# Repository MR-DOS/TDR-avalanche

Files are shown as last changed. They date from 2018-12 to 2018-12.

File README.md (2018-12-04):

# TDR-avalanche
----
## Description
Simple flat-top avalanche pulser with integrated power supply for the avalanche transistor circuit and trigger circuitry. 

----
## Overview
This pulser was made in hope to use it to measure reflections on cables. However, using the transistor 2SC5773, it was not possible to obtain faster risetime than about 700 ps. This allows to measure reflections, but the resolution is quite limited due to the shape of the pulse (slow risetime and a backlash after the falling edge). Maybe using some other transistor and changing the compensation circuitry, it could be made better. Since there are many PECL buffers with rise and fall times faster than 200 ps (and reproducible), the next one will use some IC to generate the pulses. Also, generating short rectangular pulse is not very good if you want to postprocess the data, because you would need to run a decorrelation to find out what is happening on the cable. Using a long rectangular pulse (with infinitesimally fast edges) where all of the reflected energy comes back before the falling edge allows you to derive the signal which in turn gives you impulse response.

----
## Features
### Power supplies
The pulser contains a 40V power supply followed by denoising network and 6V - 35V regulated linear supply to set the avalanche voltage. The whole board is powered from 5V using Mini USB-B, consuming less than 100 mA.

### Avalanche pulser
The avalanche pulser uses 2SC5773 transistor (6V NPN, fT=10.8 GHz @ 50 mA). The compensation circuitry makes the output pulse a nice clean rectangular pulse with a flat top with no visible ringing (invisible with 1 GHz oscilloscope, to be precise), however there is a not very nice backlash after the falling edge (see pictures). The transistor does not self-avalanche when set properly, it has to be triggered by external source. I used 8-10 kHz triggering during the development and use. There are 2 SMA connectors, one for coaxial cable where energy for the pulse is stored (length of the cable determines length of the pulse) and one where the pulses are output.

### Trigger circuitry
The trigger circuitry triggers avalanche on rising edge of the input trigger signal. There is RC circuit which sets the time between the trigger and avalanche. However, it seems to have quite large jitter. There is also trigger output which you can connect to scilloscope (the avalanche happens on falling edge of the TRIG OUT). The trigger circuitry can be inhibited using the jumper JP1 when tuning the avalanche voltage.

### Attenuators
There are 2 attenuator sections giving 11.3 and 7.9 dB attenuation. The first one is mandatory as it is an impedance matching circuit. The second one is just a normal attenuator and can be omitted.

----
## How to use it as a simple standalone time-domain reflectometer
Connect square wave generator to the SYNC\_IN port. Connect an oscilloscope to the SYNC\_OUT port and to the PULSE\_OUT port.
Connect the coaxial cable to be measured to the STORAGE_COAX port. The cable MUST NOT have any shorts in it or any low impedance termination, because it is connected to the collector network and it would load the 200k resistor and the transistor would not avalanche. This severely limits the useability, so this mode is not recommended.

----
## How to use it as a pulser for general use
Connect square wave generator to the SYNC\_IN port.
Connect storage coaxial cable to the STORAGE_COAX port. You should use some 50 Ohm cable with low losses, ideally some rigid or semirigid cable. I used RG-174 because I had a lot of it on hand and the circuit is tweaked for use with the RG-174 (I used about one meter of the cable which gave me about 8 ns long pulse). Connect the PULSE\_OUT port to anything you want (50 Ohm terminated).

----
## Images
Oscillogram of the whole pulse:
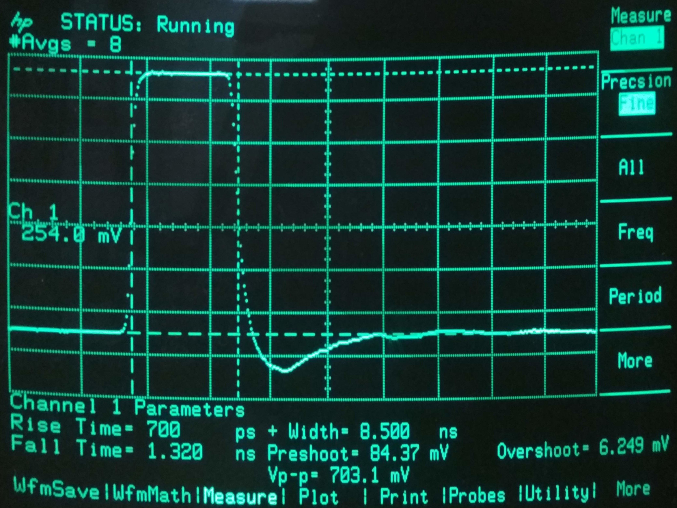
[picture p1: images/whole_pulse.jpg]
Oscillogram of the whole pulse

Oscillogram of the rising edge:
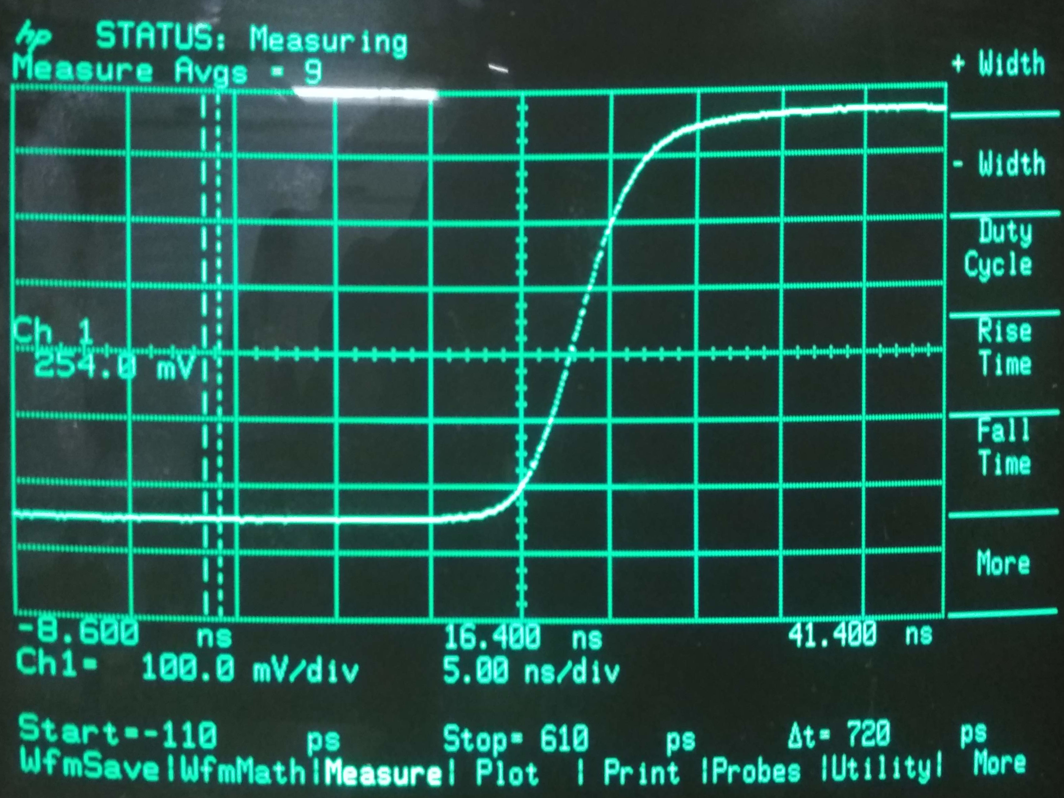
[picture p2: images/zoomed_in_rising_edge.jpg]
Oscillogram of the rising edge

Oscillogram of the zoomed in pulse:
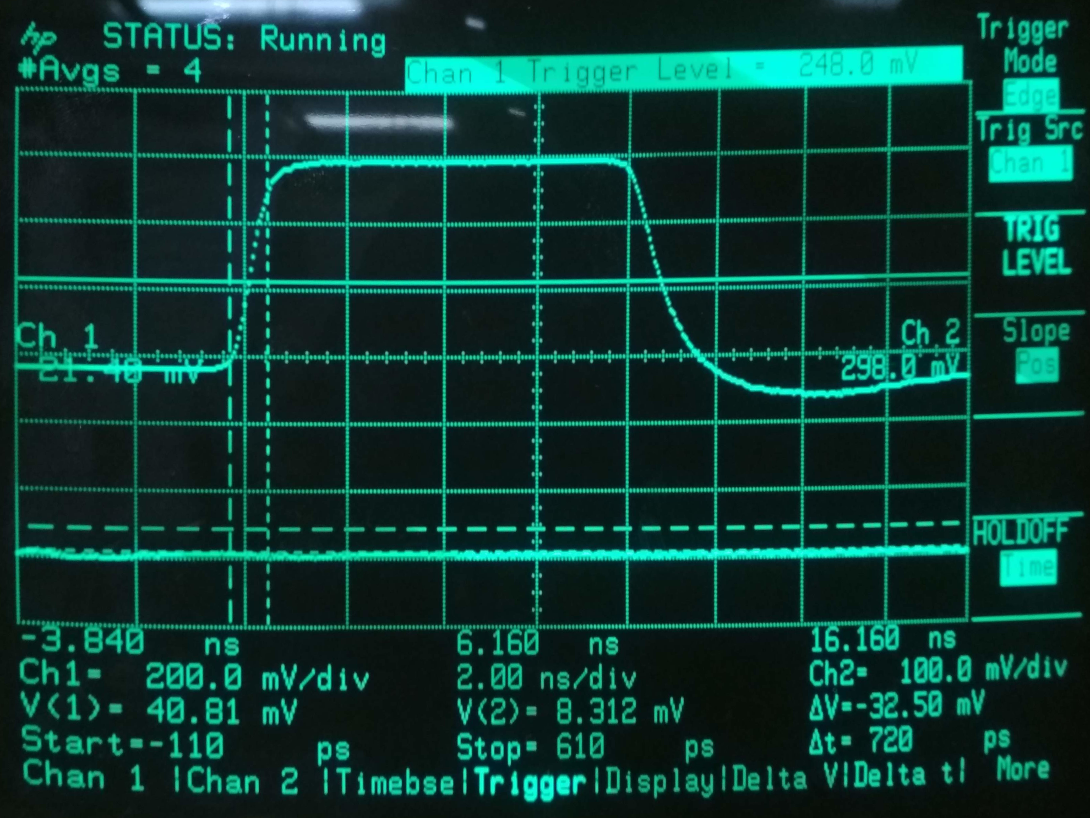
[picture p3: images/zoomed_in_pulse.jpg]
Oscillogram of the zoomed in pulse

Picture of the made and assembled PCB:
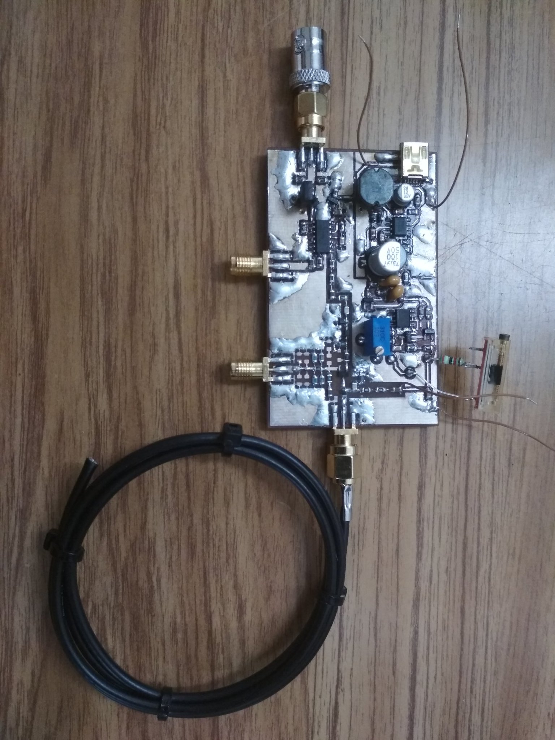
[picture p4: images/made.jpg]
Picture of the made and assembled PCB

Picture of the PCB connected to oscilloscope and generator:
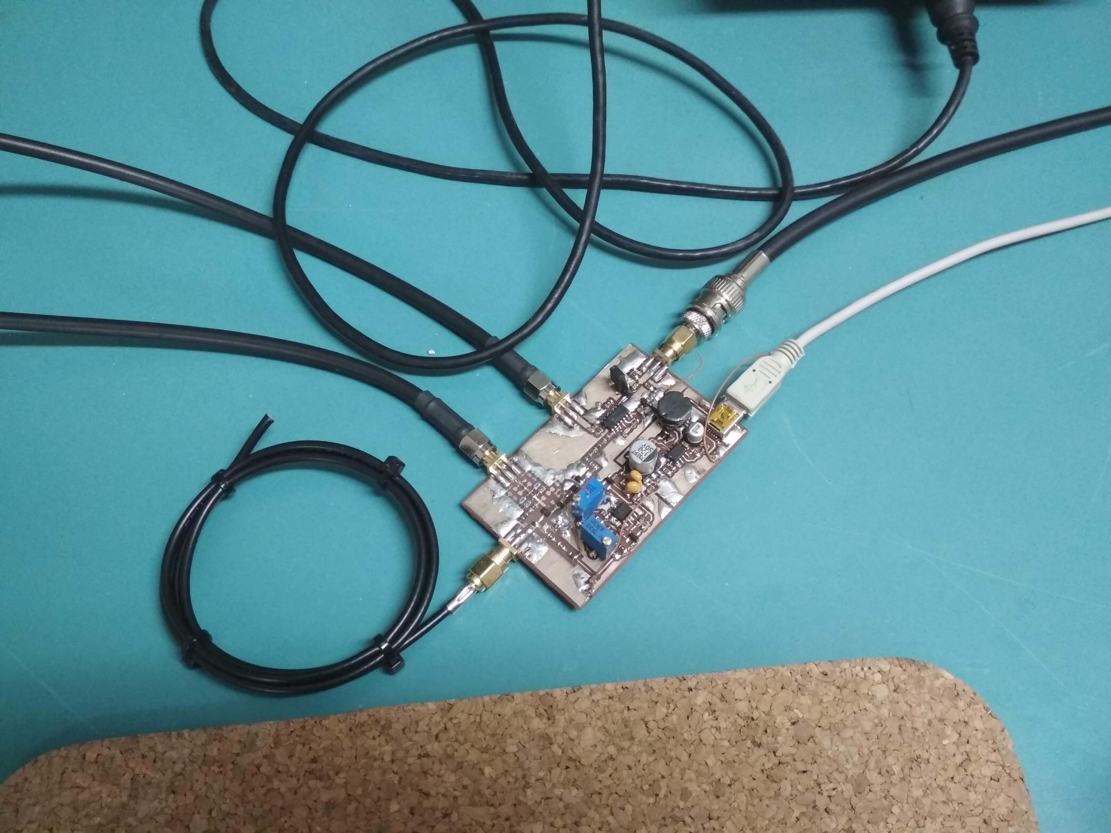
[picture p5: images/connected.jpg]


----
## Reference
[AN-94: Slew Rate Verification for Wideband Amplifiers](https://www.analog.com/media/en/technical-documentation/application-notes/an94f.pdf)

[AN-72: A Seven-Nanosecond Comparator for Single Supply Operation](https://www.analog.com/media/en/technical-documentation/application-notes/an72f.pdf)

[Tweet with photo of the etched PCB](https://twitter.com/polasek_petr/status/1063875099940532225)

[Tweet with photos of the etched, drilled and assembled PCB](https://twitter.com/polasek_petr/status/1064328075725426688)

[Tweet with measured output of the circuit](https://twitter.com/polasek_petr/status/1064698462539866112)

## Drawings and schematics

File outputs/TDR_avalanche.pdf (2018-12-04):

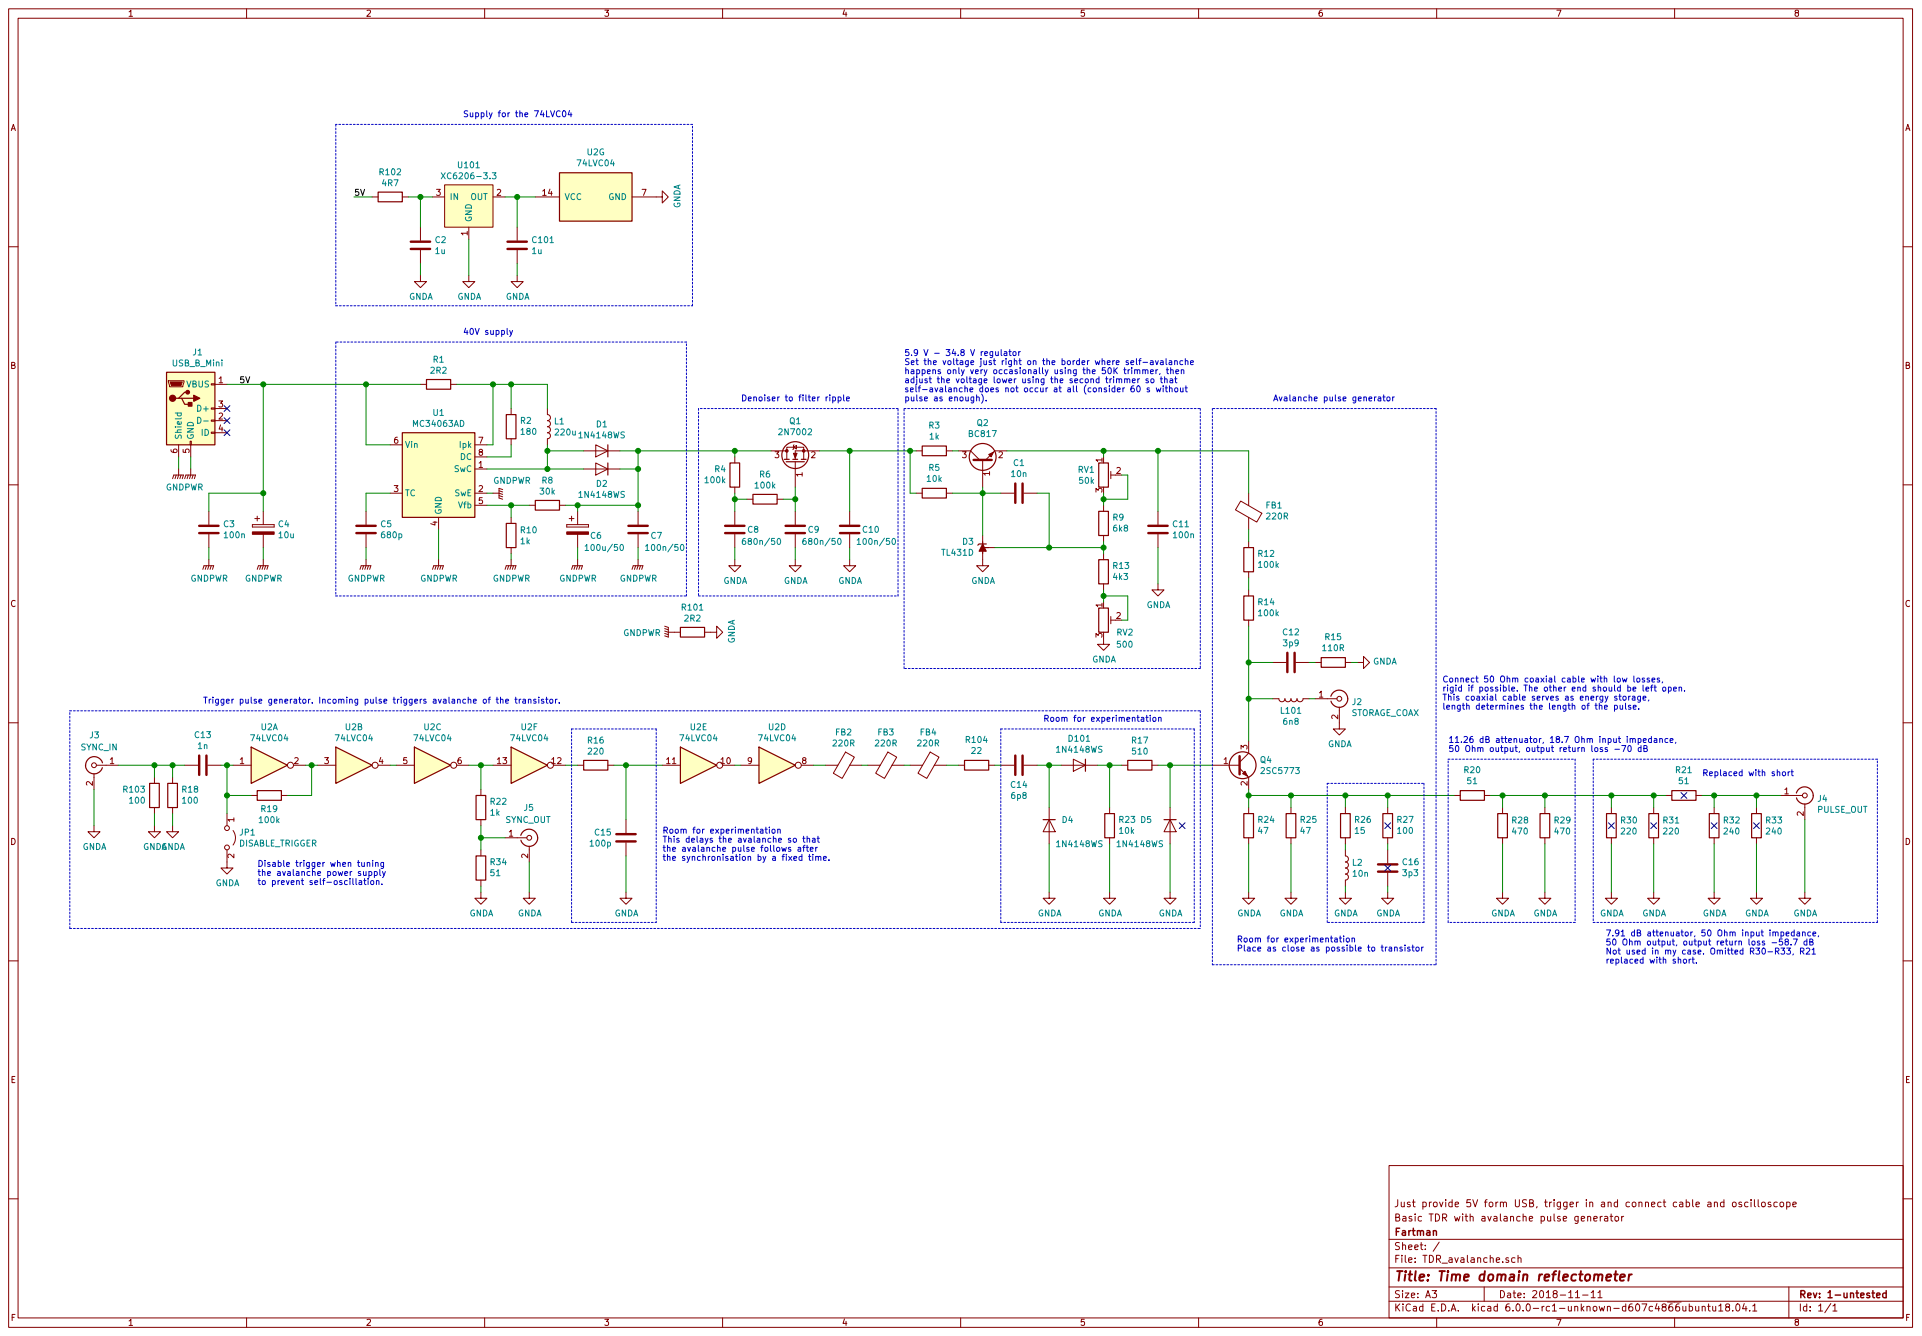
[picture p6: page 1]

5.9 V - 34.8 V regulator
Set the voltage just right on the border where self-avalanche
happens only very occasionally using the 50K trimmer, then
adjust the voltage lower using the second trimmer so that
self-avalanche does not occur at all (consider 60 s without
pulse as enough).

This coaxial cable serves as energy storage,

Trigger pulse generator. Incoming pulse triggers avalanche of the transistor.

length determines the length of the pulse. D101
Room for experimentation

J3 SYNC_IN
the synchronisation by a fixed time. 1

11.26 dB attenuator, 18.7 Ohm input impedance,
50 Ohm output, output return loss -70 dB

Place as close as possible to transistor R26

This delays the avalanche so that
the avalanche pulse follows after

the avalanche power supply

7.91 dB attenuator, 50 Ohm input impedance,
50 Ohm output, output return loss -58.7 dB
Not used in my case. Omitted R30-R33, R21

Just provide 5V form USB, trigger in and connect cable and oscilloscope
File: TDR_avalanche.sch Sheet: / Fartman Basic TDR with avalanche pulse generator

Id: 1/1 Title: Time domain reflectometer

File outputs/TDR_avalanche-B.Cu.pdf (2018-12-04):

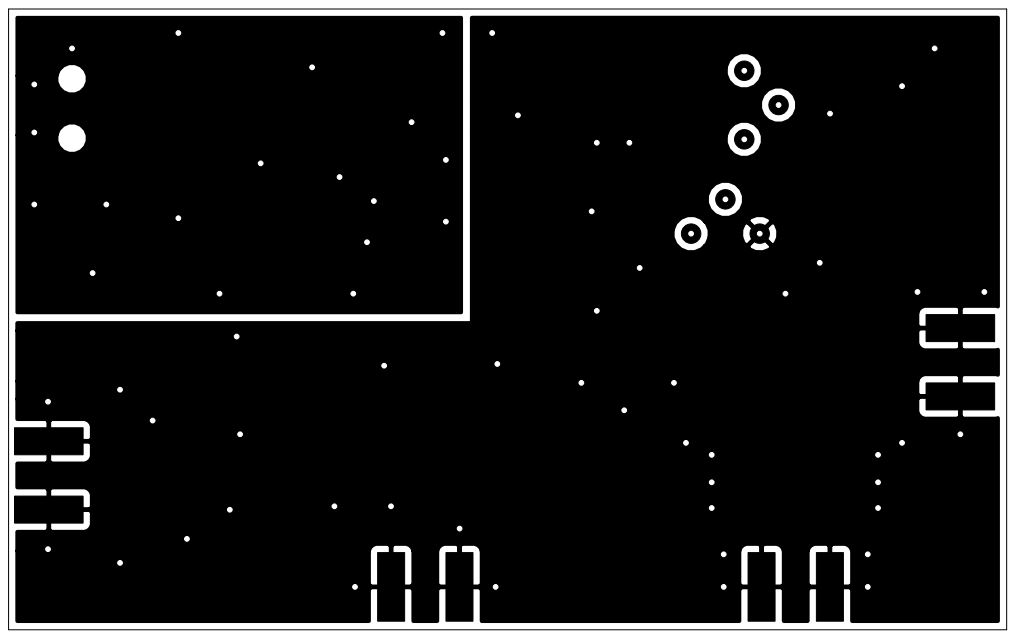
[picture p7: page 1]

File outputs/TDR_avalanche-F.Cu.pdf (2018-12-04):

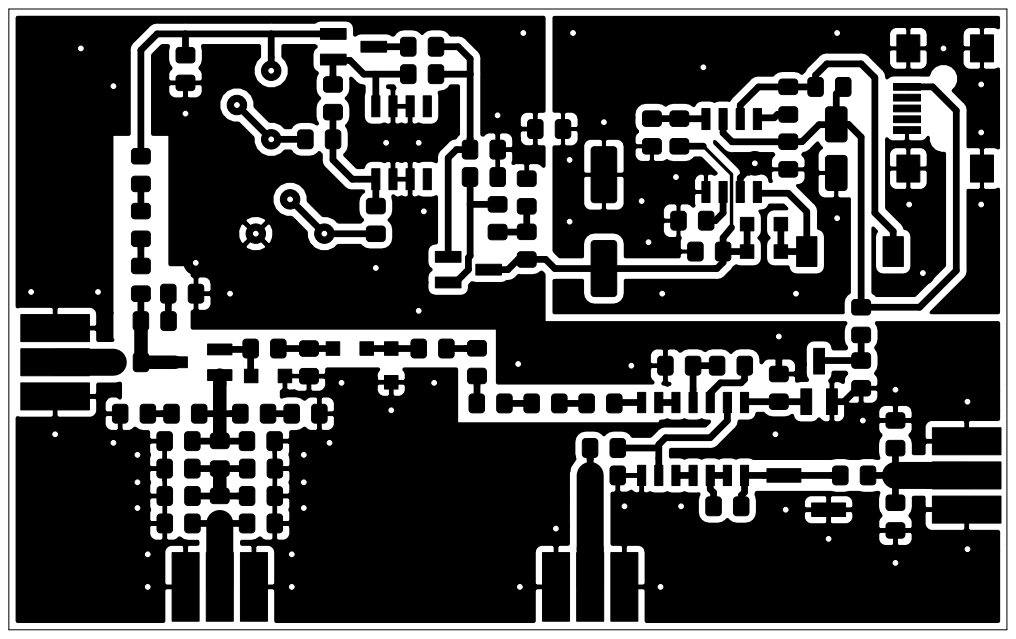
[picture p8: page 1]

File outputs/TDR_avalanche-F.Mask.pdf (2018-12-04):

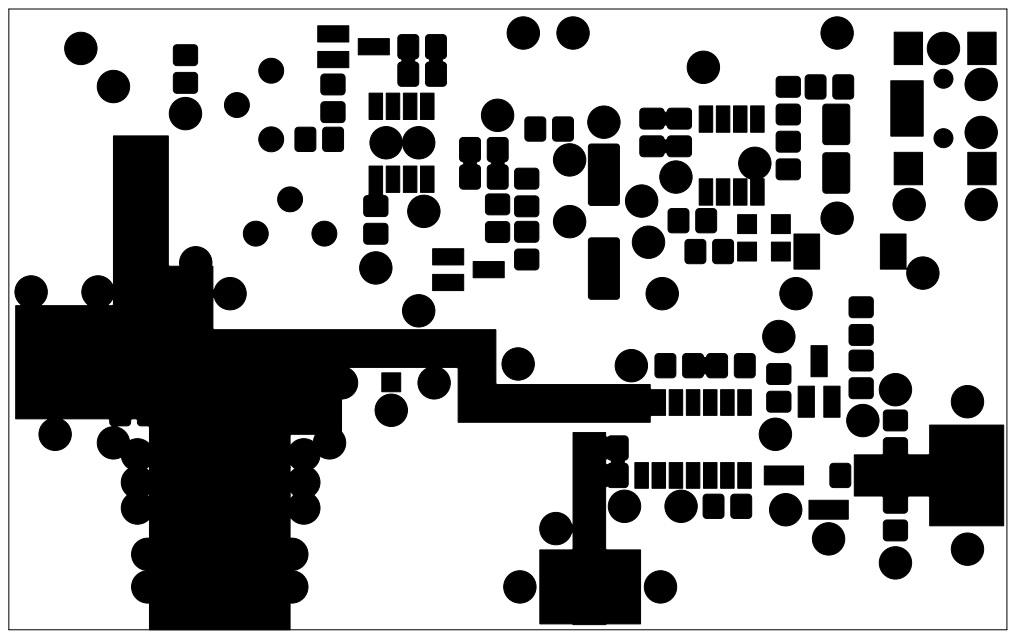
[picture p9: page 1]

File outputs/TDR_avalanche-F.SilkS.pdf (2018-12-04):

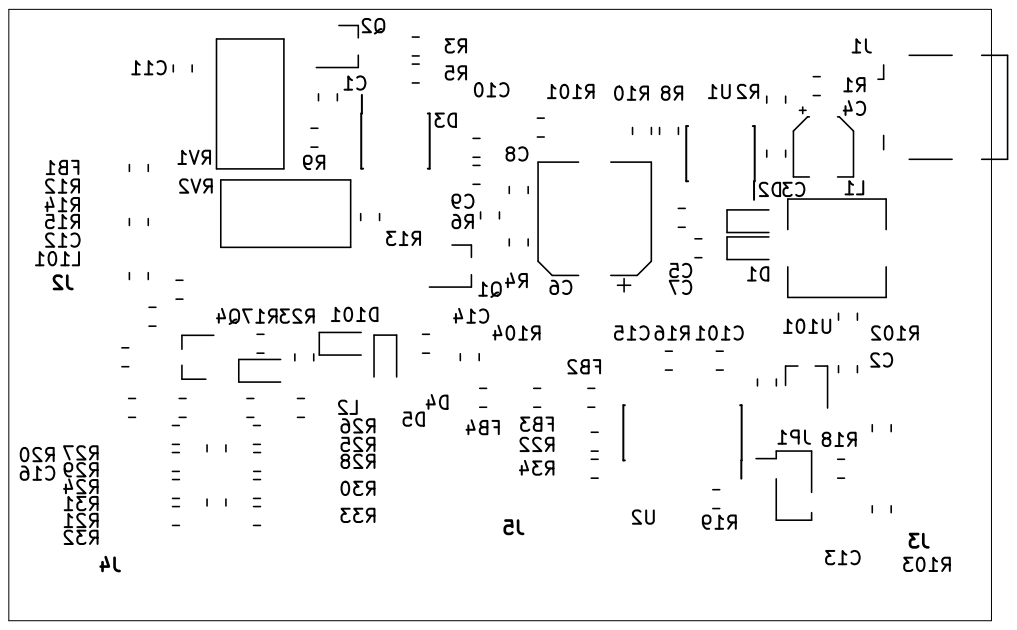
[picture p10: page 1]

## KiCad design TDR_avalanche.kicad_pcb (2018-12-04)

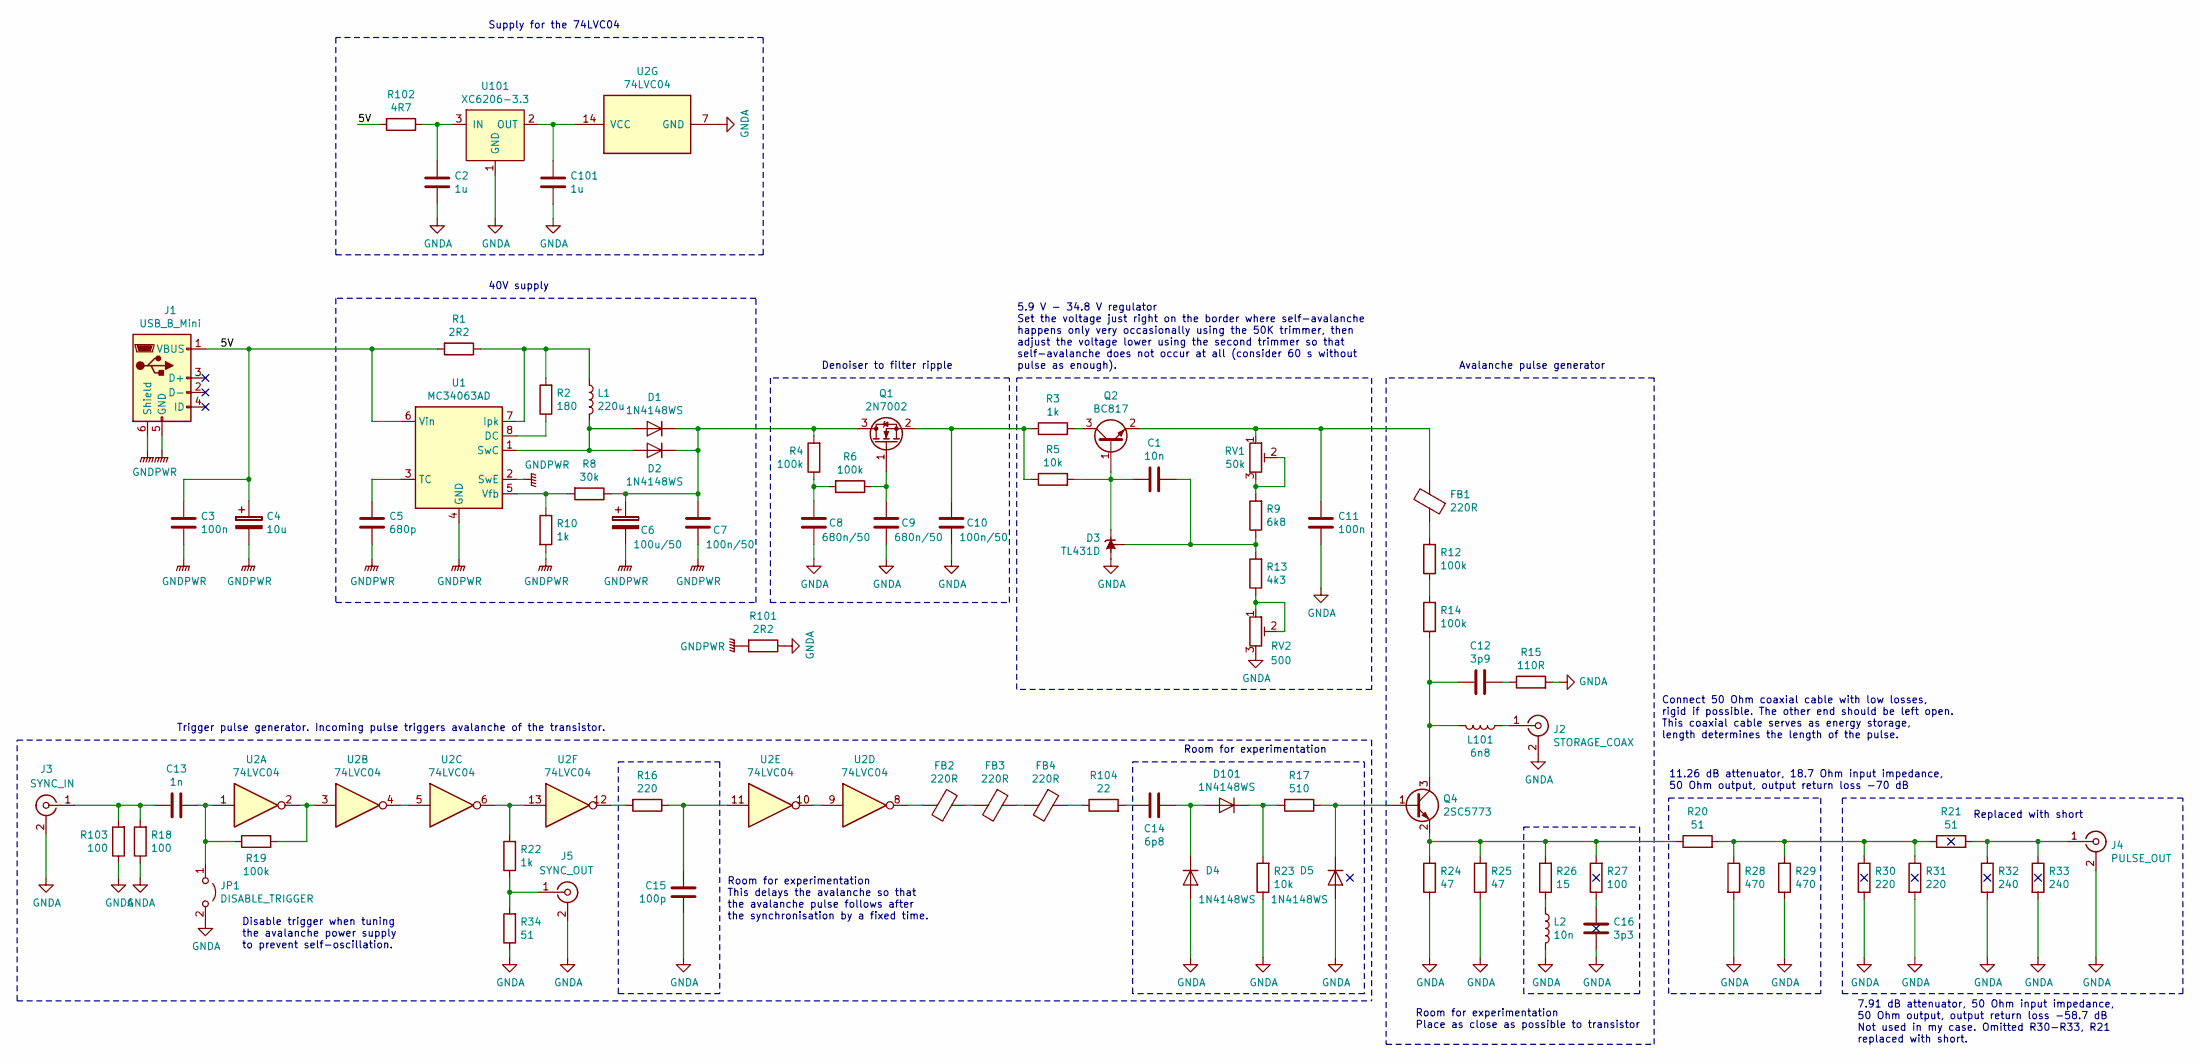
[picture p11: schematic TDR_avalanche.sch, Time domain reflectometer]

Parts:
C1: 10n; C_0805_2012Metric_Pad1.15x1.40mm_HandSolder
C2, C101: 1u; C_0805_2012Metric_Pad1.15x1.40mm_HandSolder
C3, C11: 100n; C_0805_2012Metric_Pad1.15x1.40mm_HandSolder
C4: 10u; CP_Elec_4x5.3
C5: 680p; C_0805_2012Metric_Pad1.15x1.40mm_HandSolder
C6: 100u/50; CP_Elec_8x6.9
C7, C10: 100n/50; C_0805_2012Metric_Pad1.15x1.40mm_HandSolder
C8, C9: 680n/50; C_0805_2012Metric_Pad1.15x1.40mm_HandSolder
C12: 3p9; C_0805_2012Metric_Pad1.15x1.40mm_HandSolder
C13: 1n; C_0805_2012Metric_Pad1.15x1.40mm_HandSolder
C14: 6p8; C_0805_2012Metric_Pad1.15x1.40mm_HandSolder
C15: 100p; C_0805_2012Metric_Pad1.15x1.40mm_HandSolder
C16: 3p3; C_0805_2012Metric_Pad1.15x1.40mm_HandSolder
D1, D2, D4, D5, D101: 1N4148WS; D_SOD-323_HandSoldering
D3: TL431D; SOIC-8_3.9x4.9mm_P1.27mm
FB1, FB2, FB3, FB4: 220R; L_0805_2012Metric_Pad1.15x1.40mm_HandSolder
J1: USB_B_Mini; USB_Mini-B_Lumberg_2486_01_Horizontal
J2: STORAGE_COAX; Molex_SMA_Jack_Edge_Mount_Chinese
J3: SYNC_IN; Molex_SMA_Jack_Edge_Mount_Chinese
J4: PULSE_OUT; Molex_SMA_Jack_Edge_Mount_Chinese
J5: SYNC_OUT; Molex_SMA_Jack_Edge_Mount_Chinese
JP1: DISABLE_TRIGGER; PinHeader_1x02_P2.54mm_Vertical_SMD_Pin1Right
L1: 220u; L_7.3x7.3_H4.5
L2: 10n; L_0805_2012Metric_Pad1.15x1.40mm_HandSolder
L101: 6n8; L_0805_2012Metric_Pad1.15x1.40mm_HandSolder
Q1: 2N7002; SOT-23_Handsoldering
Q2: BC817; SOT-23_Handsoldering
Q4: 2SC5773; SC-59_Handsoldering
R1, R101: 2R2; R_0805_2012Metric_Pad1.15x1.40mm_HandSolder
R2: 180; R_0805_2012Metric_Pad1.15x1.40mm_HandSolder
R3, R10, R22: 1k; R_0805_2012Metric_Pad1.15x1.40mm_HandSolder
R4, R6, R12, R14, R19: 100k; R_0805_2012Metric_Pad1.15x1.40mm_HandSolder
R5, R23: 10k; R_0805_2012Metric_Pad1.15x1.40mm_HandSolder
R8: 30k; R_0805_2012Metric_Pad1.15x1.40mm_HandSolder
R9: 6k8; R_0805_2012Metric_Pad1.15x1.40mm_HandSolder
R13: 4k3; R_0805_2012Metric_Pad1.15x1.40mm_HandSolder
R15: 110R; R_0805_2012Metric_Pad1.15x1.40mm_HandSolder
R16, R30, R31: 220; R_0805_2012Metric_Pad1.15x1.40mm_HandSolder
R17: 510; R_0805_2012Metric_Pad1.15x1.40mm_HandSolder
R18, R27, R103: 100; R_0805_2012Metric_Pad1.15x1.40mm_HandSolder
R20, R21, R34: 51; R_0805_2012Metric_Pad1.15x1.40mm_HandSolder
R24, R25: 47; R_0805_2012Metric_Pad1.15x1.40mm_HandSolder
R26: 15; R_0805_2012Metric_Pad1.15x1.40mm_HandSolder
R28, R29: 470; R_0805_2012Metric_Pad1.15x1.40mm_HandSolder
R32, R33: 240; R_0805_2012Metric_Pad1.15x1.40mm_HandSolder
R102: 4R7; R_0805_2012Metric_Pad1.15x1.40mm_HandSolder
R104: 22; R_0805_2012Metric_Pad1.15x1.40mm_HandSolder
RV1: 50k; Potentiometer_Bourns_3296Y_Vertical
RV2: 500; Potentiometer_Bourns_3296Y_Vertical
U1: MC34063AD; SOIC-8_3.9x4.9mm_P1.27mm
U2: 74LVC04; SOIC-14_3.9x8.7mm_P1.27mm
U101: XC6206-3.3; SOT-23_Handsoldering

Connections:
/5V: C3.1, C4.1, J1.1 (VBUS), R1.2, R102.2, U1.6 (Vin)
GNDA: C2.2, C8.2, C9.2, C10.2, C11.2, C15.2, C16.1, C101.2, D3.2 (A), D3.3 (A), D3.6 (A), D3.7 (A), D4.2 (A), D5.2 (A), J2.2 (Ext), J3.2 (Ext), J4.2 (Ext), J5.2 (Ext), JP1.2 (B), L2.2, R15.2, R18.1, R23.1, R24.1, R25.1, R28.2, R29.2, R30.2, R31.2, R32.2, R33.2, R34.1, R101.1, R103.1, RV2.3, U2.7 (GND), U101.1 (GND)
GNDPWR: C3.2, C4.2, C5.2, C6.2, C7.2, J1.5 (GND), J1.6 (Shield), R10.2, R101.2, U1.2 (SwE), U1.4 (GND)
unnamed: C1.1, D3.8 (REF), R9.1, R13.2
unnamed: C1.2, D3.1 (K), Q2.1 (B), R5.2
unnamed: C2.1, R102.1, U101.3 (IN)
unnamed: C5.1, U1.3 (TC)
unnamed: C6.1, C7.1, D1.1 (K), D2.1 (K), Q1.3 (D), R4.2, R8.1
unnamed: C8.1, R4.1, R6.2
unnamed: C9.1, Q1.1 (G), R6.1
unnamed: C10.1, Q1.2 (S), R3.1, R5.1
unnamed: C11.1, FB1.2, Q2.2 (E), RV1.1
unnamed: C12.1, R15.1
unnamed: C12.2, L101.2, Q4.3, R14.1
unnamed: C13.1, JP1.1 (A), R19.1, U2.1
unnamed: C13.2, J3.1 (In), R18.2, R103.2
unnamed: C14.1, D4.1 (K), D101.2 (A)
unnamed: C14.2, R104.2
unnamed: C15.1, R16.1, U2.11
unnamed: C16.2, R27.1
unnamed: C101.1, U2.14 (VCC), U101.2 (OUT)
unnamed: D1.2 (A), D2.2 (A), L1.2, U1.1 (SwC)
unnamed: D5.1 (K), Q4.1, R17.1
unnamed: D101.1 (K), R17.2, R23.2
unnamed: FB1.1, R12.2
unnamed: FB2.1, FB3.2
unnamed: FB2.2, U2.8
unnamed: FB3.1, FB4.2
unnamed: FB4.1, R104.1
unnamed: J2.1 (In), L101.1
unnamed: J4.1 (In), R21.2, R32.1, R33.1
unnamed: J5.1 (In), R22.1, R34.2
unnamed: L1.1, R1.1, R2.2, U1.7 (Ipk)
unnamed: L2.1, R26.1
unnamed: Q2.3 (C), R3.2
unnamed: Q4.2, R20.1, R24.2, R25.2, R26.2, R27.2
unnamed: R2.1, U1.8 (DC)
unnamed: R9.2, RV1.2, RV1.3
unnamed: R8.2, R10.1, U1.5 (Vfb)
unnamed: R12.1, R14.2
unnamed: R13.1, RV2.1, RV2.2
unnamed: R16.2, U2.12
unnamed: R19.2, U2.2, U2.3
unnamed: R20.2, R21.1, R28.1, R29.1, R30.1, R31.1
unnamed: R22.2, U2.6, U2.13
unnamed: U2.4, U2.5
unnamed: U2.9, U2.10

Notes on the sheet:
11.26 dB attenuator, 18.7 Ohm input impedance, 50 Ohm output, output return loss -70 dB
Room for experimentation
Room for experimentation Place as close as possible to transistor
7.91 dB attenuator, 50 Ohm input impedance, 50 Ohm output, output return loss -58.7 dB Not used in my case. Omitted R30-R33, R21 replaced with short.
Room for experimentation This delays the avalanche so that the avalanche pulse follows after the synchronisation by a fixed time.
40V supply
Denoiser to filter ripple
5.9 V - 34.8 V regulator Set the voltage just right on the border where self-avalanche happens only very occasionally using the 50K trimmer, then adjust the voltage lower using the second trimmer so that self-avalanche does not occur at all (consider 60 s without pulse as enough).
Trigger pulse generator. Incoming pulse triggers avalanche of the transistor.
Avalanche pulse generator
Disable trigger when tuning the avalanche power supply to prevent self-oscillation.
Connect 50 Ohm coaxial cable with low losses, rigid if possible. The other end should be left open. This coaxial cable serves as energy storage, length determines the length of the pulse.
Replaced with short
Supply for the 74LVC04

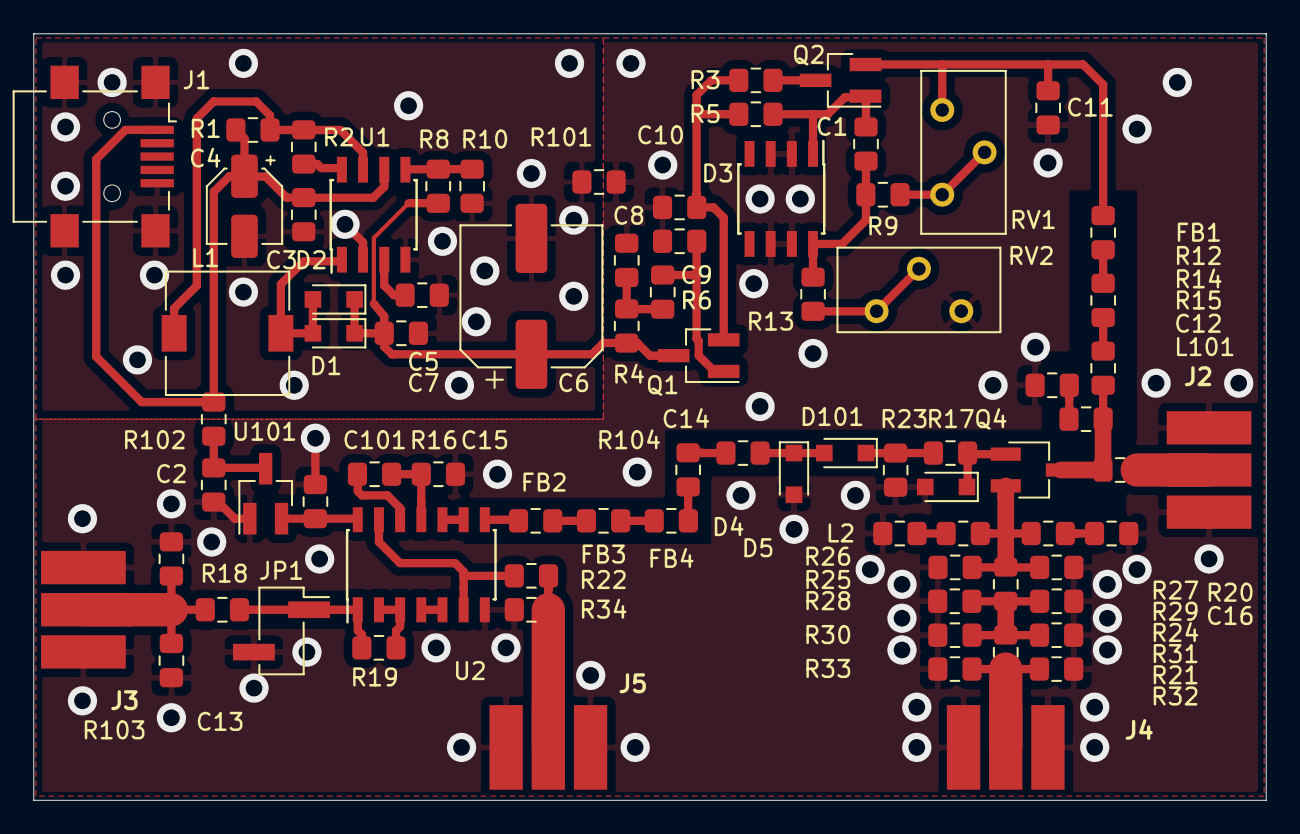
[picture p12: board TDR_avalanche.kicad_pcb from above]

Board: 2 copper layers, 73.9 x 46.0 mm, 80 parts (0 on the bottom side), 47 nets.
